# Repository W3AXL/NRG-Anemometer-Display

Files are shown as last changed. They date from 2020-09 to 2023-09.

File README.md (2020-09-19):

# NRG Anemometer Display
A compact, cheap interface unit for NRG #40C 3-cup anemometers.

<p float="left">
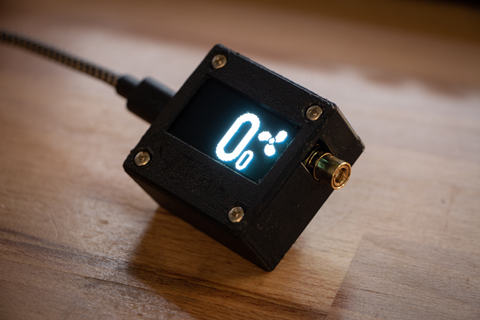
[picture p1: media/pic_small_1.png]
  
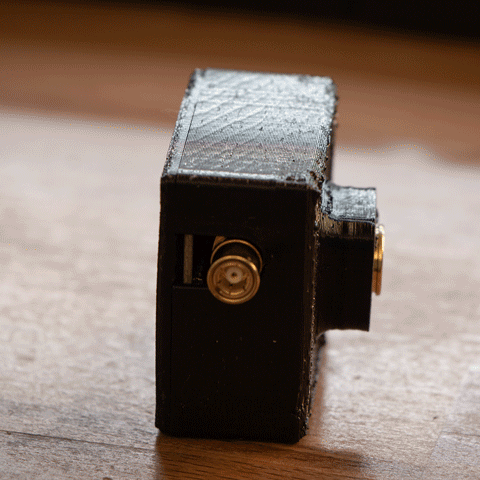
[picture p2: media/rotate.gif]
   
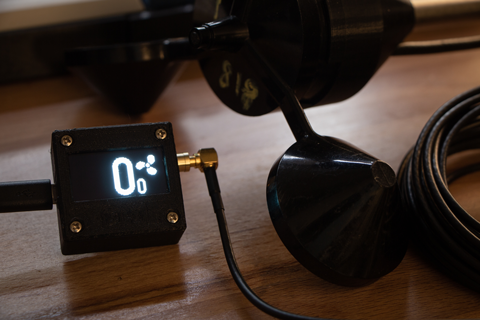
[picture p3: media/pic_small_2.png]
   
</p>

This project started because I found a great deal on some NRG anemometers on eBay. Two for $40 was hard to turn down, especially because each unit is calibrated from the factory and said calibration is freely available on [NRG's website](https://www.nrgsystems.com/support/product-support/calibration-reports/).

The heavy lifting of the circuit was already done for me - the technical whitepaper from NRG clearly illustrates an almost-complete schematic. The only real work to be done was selection of components, the MCU interfacing, and board design for a nice compact meter.

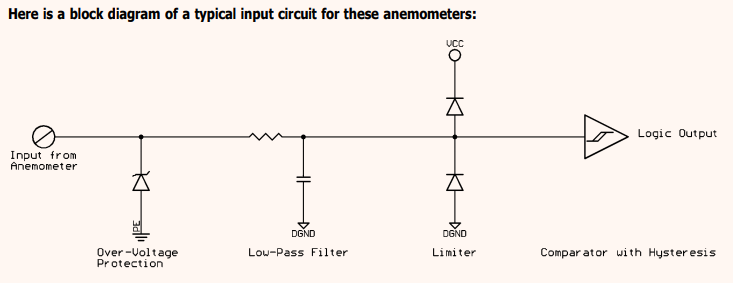
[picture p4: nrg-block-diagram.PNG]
NRG Block Diagram


I went through a lot of initial brainstorming for the interface concept - battery powered, or DC? Integrated data logging, or keep it simple? How many buttons? Should it beep at you annoyingly?

In the end, a dead-simple interface showing current and maximum wind readings was decided on. Power is provivded via a micro-USB plug, which also creates a serial port for real-time data transfer to a PC. The display is your standard run-of-the-mill eBay 1.3" OLED display, driven by I2C, and available for a few dollars all over the place. Boards were designed in Kicad and manufactured by JLCPCB. Components were sourced from Digikey, and the whole thing took a couple days to get working.



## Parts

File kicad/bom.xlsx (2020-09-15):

Ref | Qnty | Value | Cmp name | Footprint | Link | Description
C1, C2, C4, | 3 | 0.1uF | C_Small | C_0805 | Digikey (https://www.digikey.com/product-detail/en/avx-corporation/08055C104J4T2A/478-9380-1-ND/4901454) | Unpolarized capacitor, small symbol
C3, C5, C8, | 3 | 1uF | C_Small | C_0805 | Digikey (https://www.digikey.com/product-detail/en/avx-corporation/0805YC105JAT2A/478-10570-1-ND/6797609) | Unpolarized capacitor, small symbol
C6, C7, | 2 | 6.8pF | C_Small | C_0805 | Digikey (https://www.digikey.com/product-detail/en/avx-corporation/08055A6R8JAT2A/478-10540-1-ND/6797422) | Unpolarized capacitor, small symbol
D1, | 1 | 18V | D_TVS | SOD-323 | Digikey (https://www.digikey.com/product-detail/en/bourns-inc/CDSOD323-T18SC/CDSOD323-T18SCCT-ND/6679633) | Bidirectional transient-voltage-suppression diode
D2, | 1 | 3.3V | D_Zener_Small | SOD-323 | Digikey (https://www.digikey.com/product-detail/en/on-semiconductor/MM3Z3V3T1G/MM3Z3V3T1GOSCT-ND/2623467) | Zener diode, small symbol
F1, | 1 | 250mA | Fuse_Small | F_1206 | Digikey (https://www.digikey.com/product-detail/en/bel-fuse-inc/0ZCJ0025AF2E/507-1799-1-ND/4156322) | Polyfuse, 250mA hold current
J1, | 1 | OLED | Conn_01x04_Female | SMT 01x04 Female Recpt | Digikey (https://www.digikey.com/product-detail/en/samtec-inc/SLW-104-01-F-S/SAM9947-ND/6678684) | .180" Female Low Profile Socket, 0.1" Spacing
J2, | 1 | NRG | Conn_Coaxial | (Custom) Right Angle SMB Female Connector | Digikey (https://www.digikey.com/product-detail/en/adam-tech/RF3-04A-T-00-50-G/2057-RF3-04A-T-00-50-G-ND/9830852) | coaxial connector (BNC, SMA, SMB, SMC, Cinch/RCA, ...)
J3, | 1 | AVR-ISP-6 | AVR-ISP-6 | 1x6 0.1" Unsoldered Headers | n/a | Atmel 6-pin ISP connector
J4, | 1 | USB | USB_B_Micro | (Custom) Micro USB | Digikey (https://www.digikey.com/product-detail/en/amphenol-icc-fci/10118192-0001LF/609-4613-1-ND/2785378) | USB Micro Type B connector
R1, R2, R4, R6, | 4 | 10k | R_Small | R_0805 | Digikey (https://www.digikey.com/product-detail/en/yageo/RC0805FR-0710KL/311-10-0KCRCT-ND/730482) | Resistor, small symbol
R3, R5 | 2 | 100k | R_Small | R_0805 | Digikey (https://www.digikey.com/product-detail/en/yageo/RC0805FR-07100KL/311-100KCRCT-ND/730491) | Resistor, small symbol
R7, R8, | 2 | 22R | R_Small | R_0805 | Digikey (https://www.digikey.com/product-detail/en/yageo/RC0805FR-0722RL/311-22-0CRCT-ND/730682) | Resistor, small symbol
SW1, | 1 | RESET | SW_Push | PTS645 | Digikey (https://www.digikey.com/product-detail/en/c-k/PTS645SK43SMTR92-LFS/CKN9084CT-ND/1146821) | Push button switch, generic, two pins
U1, | 1 | LM321 | LM321 | SOT-23-5 | Digikey (https://www.digikey.com/product-detail/en/texas-instruments/LM321LVIDBVR/296-51261-1-ND/9745625) | Low Power Single Operational Amplifier, SOT-23-5
U2, | 1 | SN74LVC1G14DBV | SN74LVC1G14DBV | SOT-23-5 | Digikey (https://www.digikey.com/product-detail/en/texas-instruments/SN74LVC1G14DBVR/296-11607-1-ND/385746) | Single Schmitt-Trigger Inverter, SOT-23
U3, | 1 | ATmega32U4-AU | ATmega32U4-AU | TQFP-44 | Digikey (https://www.digikey.com/product-detail/en/microchip-technology/ATMEGA32U4RC-AU/ATMEGA32U4RC-AU-ND/2507982) | 16MHz, 32kB Flash, 2.5kB SRAM, 1kB EEPROM, USB 2.0, TQFP-44
U4, | 1 | XC6210B332MR-G | XC6210 | SOT-74A | Digikey (https://www.digikey.com/product-detail/en/torex-semiconductor-ltd/XC6210B332MR-G/893-1075-1-ND/2138266) | 3.3V LDO
Y1, | 1 | 8MHz | Crystal_Small | (Custom) SMD Crystal, 2-SMD | Digikey (https://www.digikey.com/product-detail/en/ndk-america-inc/NX8045GB-8-000000MHZ/644-1018-1-ND/1128890) | Two pin crystal, small symbol

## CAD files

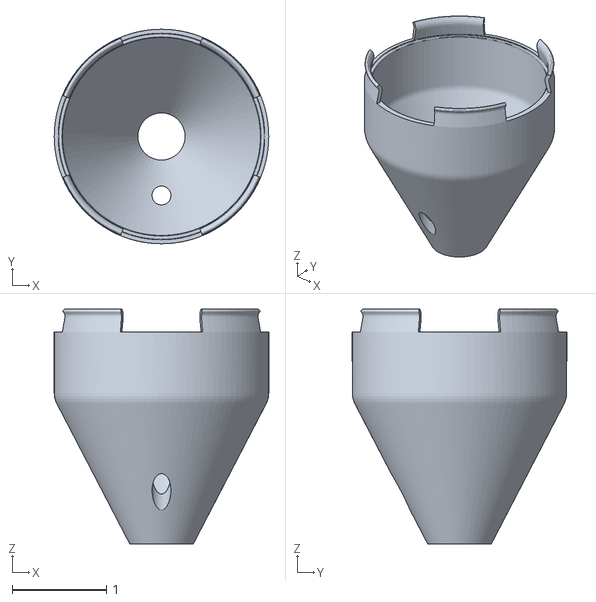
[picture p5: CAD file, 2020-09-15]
cad/anemometer shroud/shroud-revB.stl
2.28 x 2.28 x 2.49

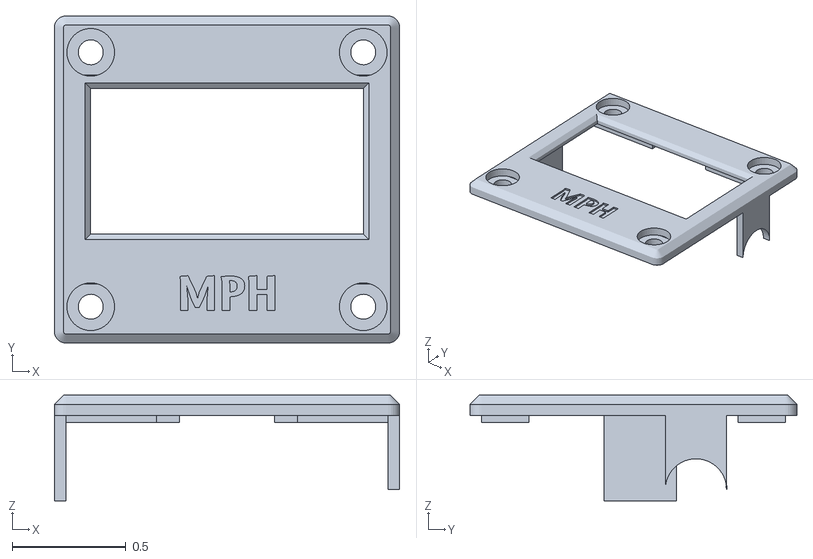
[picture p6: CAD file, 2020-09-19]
cad/enclosure/top-revA.stl
1.52 x 1.44 x 0.465

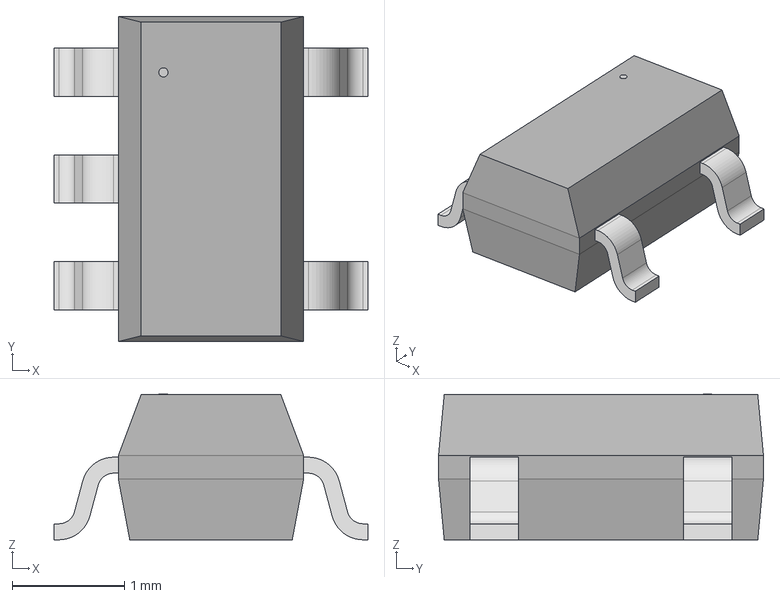
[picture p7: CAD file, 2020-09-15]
kicad/SOT-25_TOR.step
2.79 x 2.90 x 1.30 mm

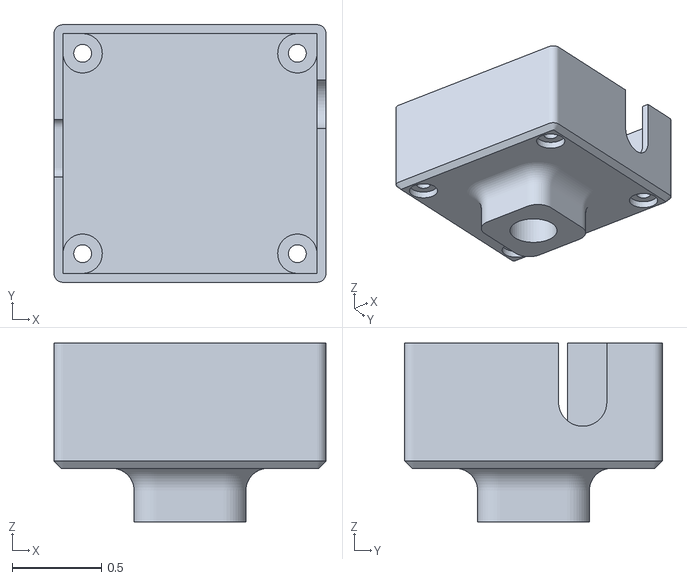
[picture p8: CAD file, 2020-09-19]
cad/enclosure/body-revA.stl
1.52 x 1.44 x 1.00

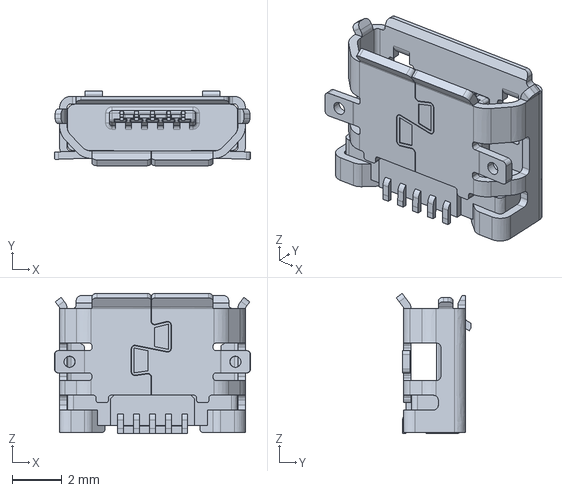
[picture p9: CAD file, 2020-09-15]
kicad/10118192C.stp
7.91 x 3.01 x 5.66 mm

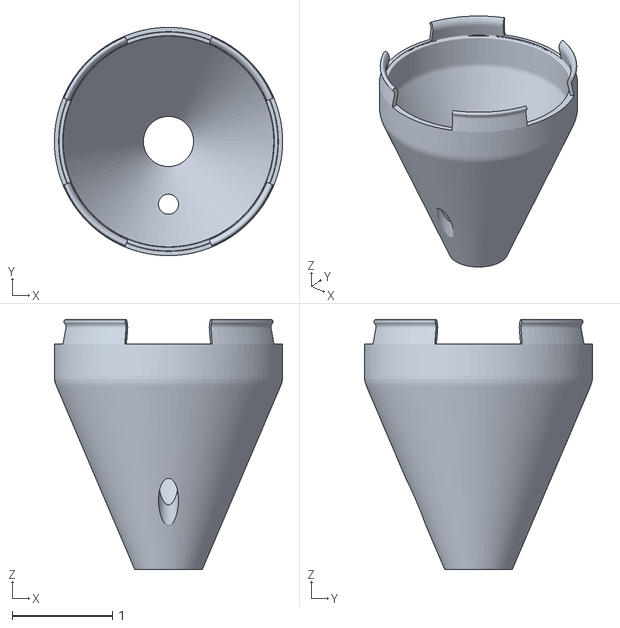
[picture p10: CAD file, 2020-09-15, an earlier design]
cad/anemometer shroud/shroud-revA.stl
2.28 x 2.28 x 2.49

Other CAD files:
kicad/SOT-25_TOR-M.step
kicad/SOT-25_TOR-L.step

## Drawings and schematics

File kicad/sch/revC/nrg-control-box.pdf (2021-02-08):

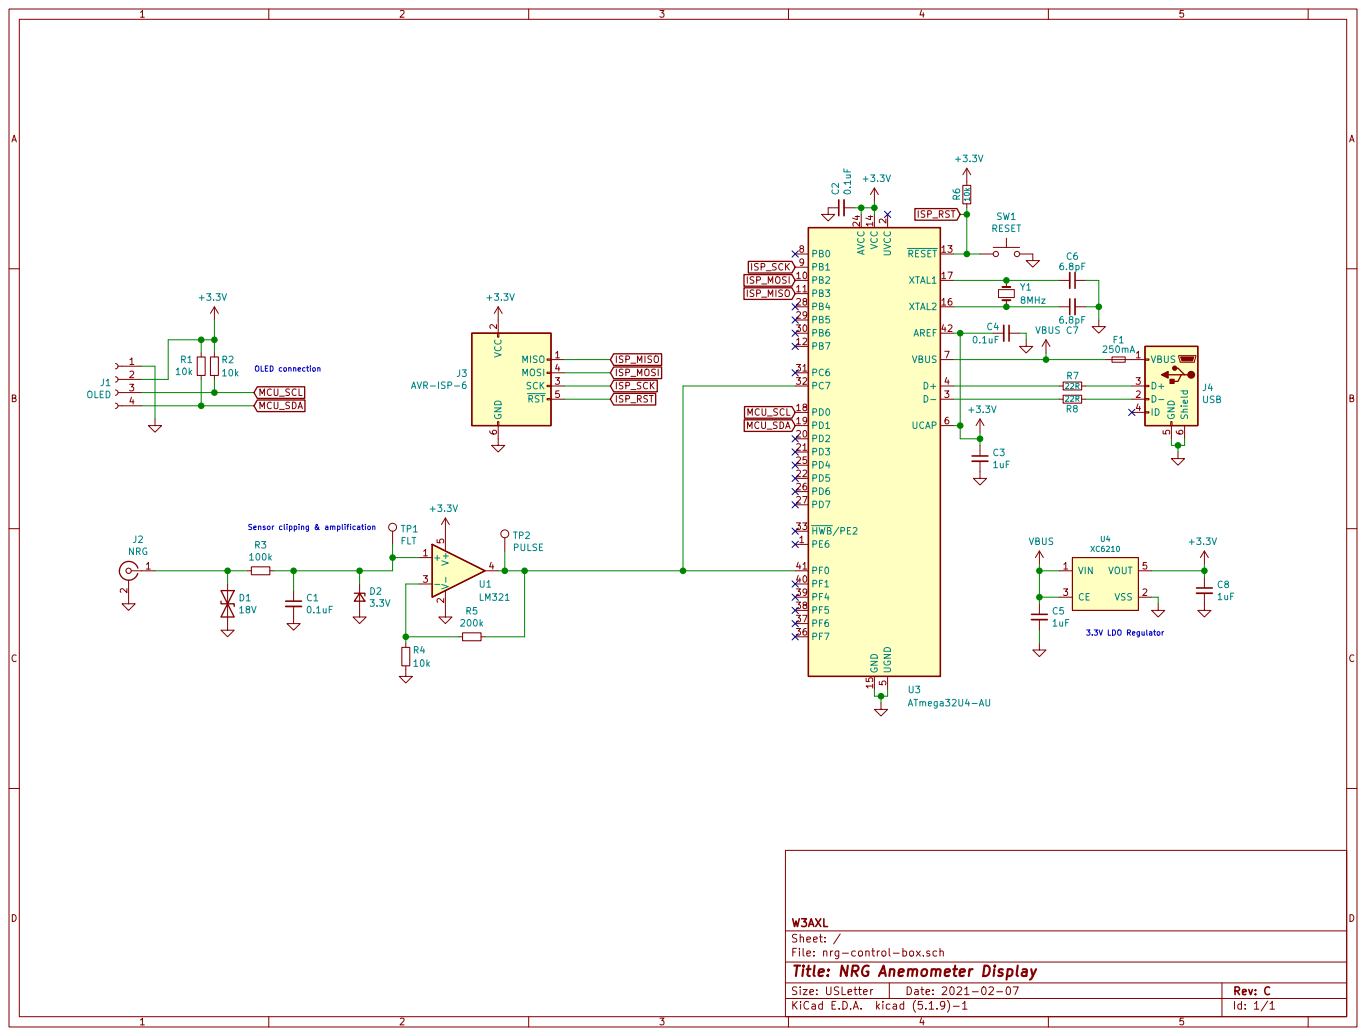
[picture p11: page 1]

2 SCK 3 MOSI 4 RST 5 GND

ISP_MISO MCU_SDA MCU_SCL
Sensor clipping & amplification OLED connection

File: nrg-control-box.sch Sheet: / W3AXL

Id: 1/1 Title: NRG Anemometer Display

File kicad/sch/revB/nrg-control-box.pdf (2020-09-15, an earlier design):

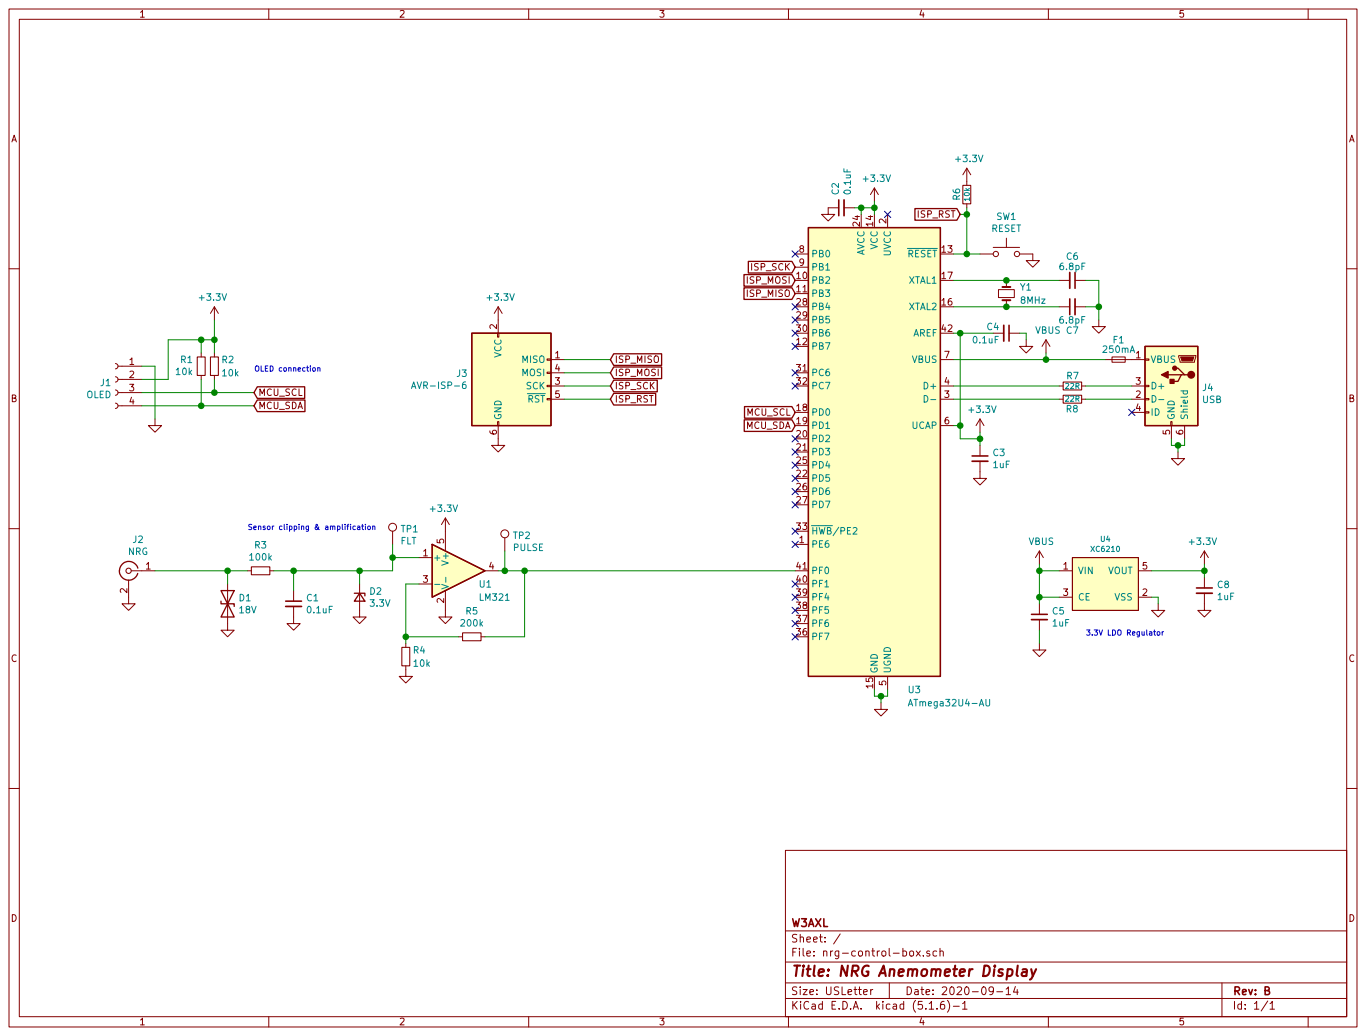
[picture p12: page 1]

2 SCK 3 MOSI 4 RST 5 GND

ISP_MISO MCU_SCL MCU_SDA
3.3V LDO Regulator OLED connection Sensor clipping & amplification

File: nrg-control-box.sch Sheet: / W3AXL

Id: 1/1 Title: NRG Anemometer Display

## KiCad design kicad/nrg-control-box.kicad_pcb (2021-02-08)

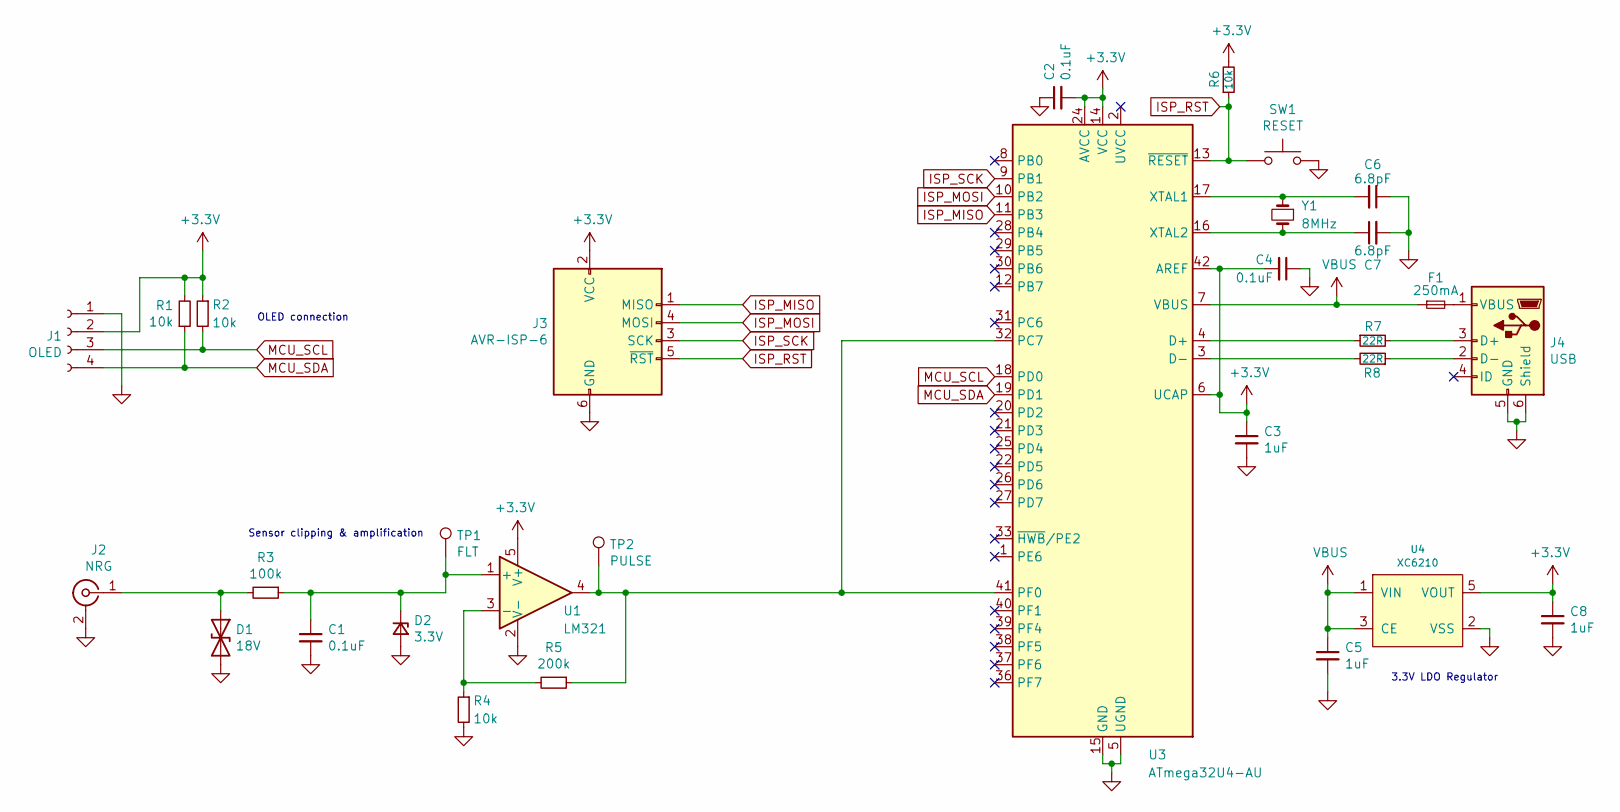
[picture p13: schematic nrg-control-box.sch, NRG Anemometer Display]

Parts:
C1, C2, C4: 0.1uF; C_0805_2012Metric_Pad1.15x1.40mm_HandSolder
C3, C5, C8: 1uF; C_0805_2012Metric_Pad1.15x1.40mm_HandSolder
C6, C7: 6.8pF; C_0805_2012Metric_Pad1.15x1.40mm_HandSolder
D1: 18V; D_SOD-323_HandSoldering
D2: 3.3V; D_SOD-323_HandSoldering
F1: 250mA; Fuse_1206_3216Metric_Pad1.42x1.75mm_HandSolder
J1: OLED; PinSocket_1x04_P2.54mm_Vertical
J2: NRG; RF3-04A-T-00-50-G
J3: AVR-ISP-6; PinSocket_1x06_P1.27mm_Vertical
J4: USB; 10118192-0001LF
R1, R2, R4, R6: 10k; R_0805_2012Metric_Pad1.15x1.40mm_HandSolder
R3: 100k; R_0805_2012Metric_Pad1.15x1.40mm_HandSolder
R5: 200k; R_0805_2012Metric_Pad1.15x1.40mm_HandSolder
R7, R8: 22R; R_0805_2012Metric_Pad1.15x1.40mm_HandSolder
SW1: RESET; SW_SPST_PTS645
TP1: FLT; TestPoint_Pad_1.0x1.0mm
TP2: PULSE; TestPoint_Pad_1.0x1.0mm
U1: LM321; SOT-23-5
U3: ATmega32U4-AU; TQFP-44_10x10mm_P0.8mm
U4: XC6210; SOT95P285X145-5N
Y1: 8MHz; NX8045GB

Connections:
+3V3: C2.2, C3.1, C4.2, C8.1, J1.2, J3.2 (VCC), R1.2, R2.1, R6.2, U1.5 (V+), U3.6 (UCAP), U3.14 (VCC), U3.24 (AVCC), U3.34 (VCC), U3.42 (AREF), U3.44 (AVCC), U4.5 (VOUT); also elsewhere on the board
GND: C1.2, C2.1, C3.2, C4.1, C5.2, C6.1, C7.2, C8.2, D1.2 (A2), D2.2 (A), J1.1, J2.2 (Ext), J3.6 (GND), J4.5 (GND), J4.6 (Shield), R4.2, SW1.2, U1.2 (V-), U3.5 (UGND), U3.15 (GND), U3.23 (GND), U3.35 (GND), U3.43 (GND), U4.2 (VSS); also elsewhere on the board
ISP_MISO: J3.1 (MISO), U3.11 (PB3)
ISP_MOSI: J3.4 (MOSI), U3.10 (PB2)
ISP_RST: J3.5 (~RST), R6.1, SW1.1, U3.13 (~RESET)
ISP_SCK: J3.3 (SCK), U3.9 (PB1)
MCU_SCL: J1.3, R2.2, U3.18 (PD0)
MCU_SDA: J1.4, R1.1, U3.19 (PD1)
unnamed: C1.1, D2.1 (K), R3.1, TP1.1, U1.1 (+)
unnamed: C6.2, U3.17 (XTAL1), Y1.1
unnamed: C7.1, U3.16 (XTAL2), Y1.2
unnamed: D1.1 (A1), J2.1 (In), R3.2
unnamed: F1.2, J4.1 (VBUS)
unnamed: J4.2 (D-), R8.1
unnamed: J4.3 (D+), R7.2
unnamed: R4.1, R5.2, U1.3 (-)
unnamed 17: R5.1, TP2.1, U1.4, U3.32 (PC7), U3.41 (PF0); also elsewhere on the board
unnamed: R7.1, U3.4 (D+)
unnamed: R8.2, U3.3 (D-)
VBUS: C5.1, F1.1, U3.7 (VBUS), U4.1 (VIN), U4.3 (CE)

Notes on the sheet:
Sensor clipping & amplification
OLED connection
3.3V LDO Regulator

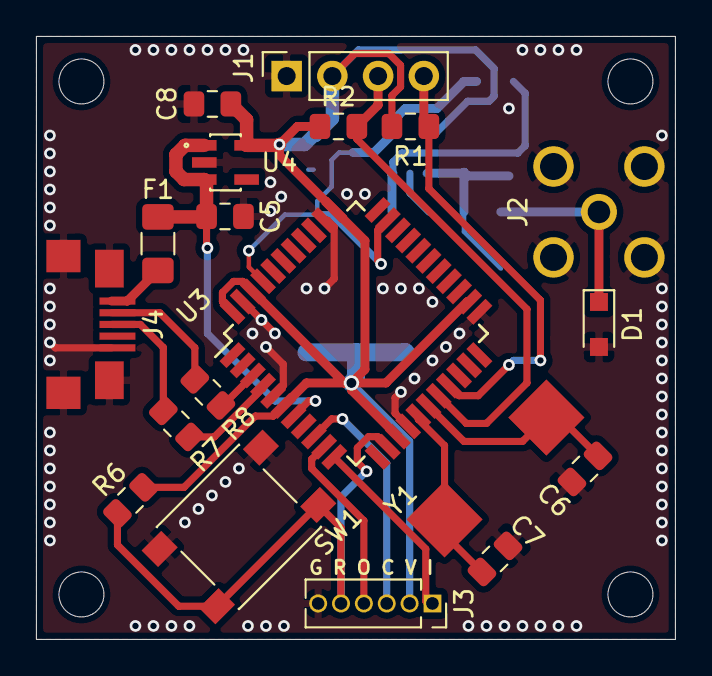
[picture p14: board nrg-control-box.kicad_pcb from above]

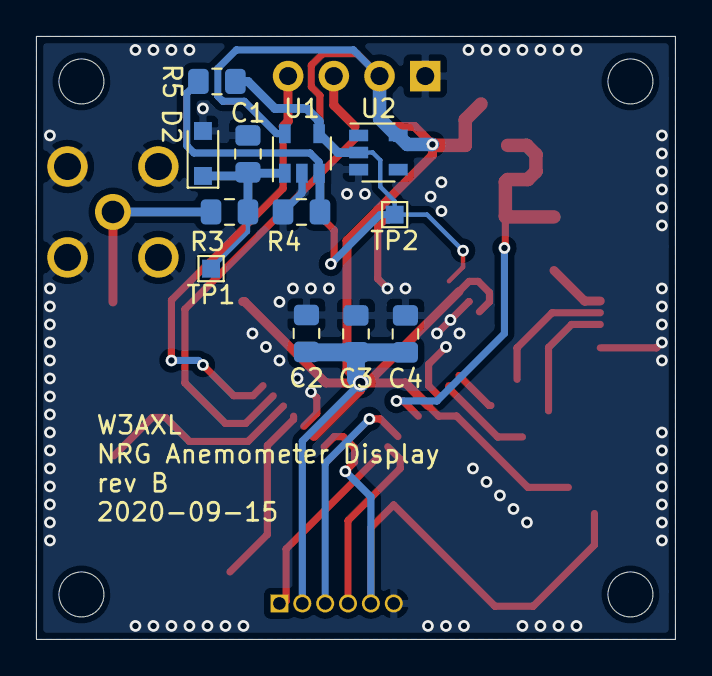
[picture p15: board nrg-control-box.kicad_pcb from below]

Board: 2 copper layers, 35.5 x 33.5 mm, 31 parts (12 on the bottom side), 20 nets.

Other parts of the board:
U2: SN74LVC1G14DBV; SOT-23-5

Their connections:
+3V3: U2.5; also elsewhere on the board
GND: U2.3; also elsewhere on the board
unnamed 17: U2.2; also elsewhere on the board

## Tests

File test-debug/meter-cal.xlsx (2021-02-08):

Freq | Meas | Ideal
1 | 3 | 2.53
3 | 6.00 | 5.92
5 | 9.00 | 9.32
7 | 13.00 | 12.71
9 | 16.00 | 16.11
11 | 20.00 | 19.50
13 | 23.00 | 22.90
15 | 26.00 | 26.30
17 | 30.00 | 29.69
19 | 33.00 | 33.09
21 | 36.00 | 36.48
23 | 40.00 | 39.88
25 | 43.00 | 43.27
27 | 47.00 | 46.67
29 | 50.00 | 50.06
31 | 53.00 | 53.46
33 |  | 56.86
35 |  | 60.25
37 |  | 63.65
39 |  | 67.04
41 |  | 70.44
43 |  | 73.83
45 |  | 77.23
47 |  | 80.63
49 |  | 84.02
51 |  | 87.42
53 |  | 90.81
55 |  | 94.21
57 |  | 97.60
59 |  | 101.00
61 |  | 104.40 | Cal Slope | 0.759
63 |  | 107.79 | Cal Offset | 0.37
65 |  | 111.19 | m/s to mph | 2.23694
67 |  | 114.58
69 |  | 117.98
71 |  | 121.37
73 |  | 124.77
75 |  | 128.17
77 |  | 131.56
79 |  | 134.96
81 |  | 138.35
83 |  | 141.75
85 |  | 145.14
87 |  | 148.54
89 |  | 151.94
91 |  | 155.33
93 |  | 158.73
95 |  | 162.12
97 |  | 165.52
99 |  | 168.91

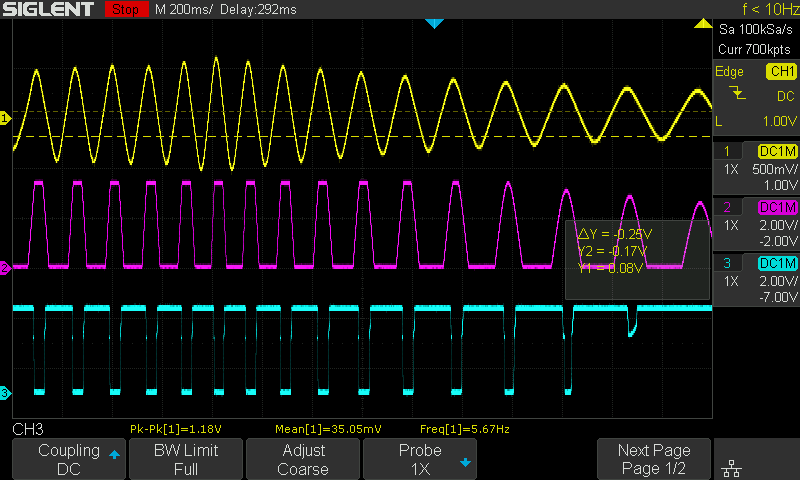
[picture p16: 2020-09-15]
test-debug/revA-analogChain-scope.png

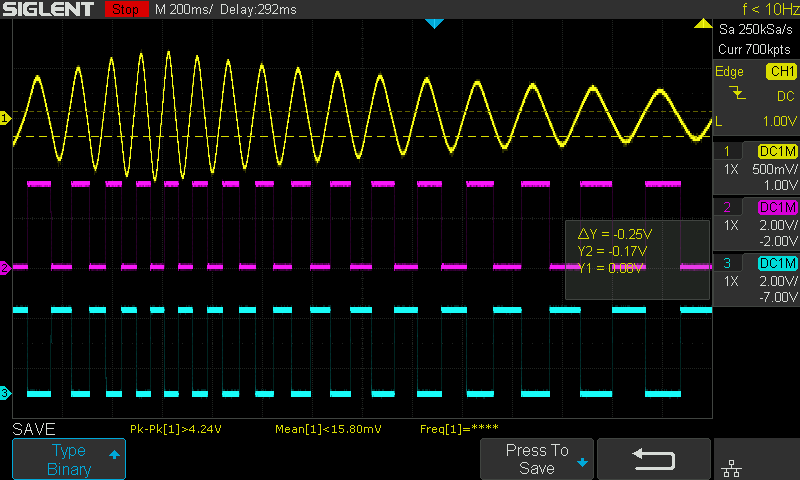
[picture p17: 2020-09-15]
test-debug/revB-analogChain-scope.png

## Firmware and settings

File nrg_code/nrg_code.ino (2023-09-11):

#include <U8g2lib.h>
#include <U8x8lib.h>

#include "fan3d.c" // fan bitmap

#include "src/FreqMeasure/FreqMeasure.h"

//#define DEBUGMODE

// compile time information
const char compile_date[] = __DATE__;
// version
const char swVersion[] = "1.1";

// Frequency Measurement Limits
#define MINFREQ 1     // approx 1.129 m/s or 2.5 mph
#define MAXFREQ 100   // approx 101.1 m/s or 226.2 mph

// Max speed reset timer in ms
#define RESETTIMEOUT (30*1000)

// Serial port report interval
#define REPORT_INTERVAL 2000

// Idle fan animation framerate
#define IDLE_ANIM_TIME 2000

// calibration data from NRG sensor
#define SLOPE 0.759
#define OFFSET 0.37

// conversion factor for m/s to mph
#define MPHFACTOR 2.23694

// storage for max freq
float maxFreq;

// storage for current speed in mph
char curSpeed;

// storage for max speed in mph
char maxSpeed;

// fan animation counter
unsigned char fanCount = 0;

// screen update timer
unsigned long lastUpdate = 0;

// serial report timer
unsigned long lastReport = 0;

// fan idle timeout
unsigned long lastIdle = 0;

// max speed reset vars
unsigned long lastMax = 0;

U8G2_SH1106_128X64_NONAME_F_HW_I2C u8g2(U8G2_R0);

void splashScreen() {
  u8g2.clearBuffer();
  u8g2.setFont(u8g2_font_9x15_tr);
  u8g2.setCursor(40,16);
  u8g2.print("Anemometer");
  u8g2.setCursor(40,30);
  u8g2.print("by W3AXL");
  u8g2.setCursor(4,44);
  u8g2.print("Version " + String(swVersion));
  u8g2.setCursor(4,58);
  u8g2.print(compile_date);
  u8g2.sendBuffer();
  // loading animation
  for (int i=0; i<100; i+=3) {
    u8g2.drawPixel(14+(i),63);
    u8g2.drawPixel(14+(i+1),63);
    u8g2.drawPixel(14+(i+2),63);
    u8g2.sendBuffer();
    switch (i%4) {
      case 0:
        u8g2.drawXBM(4,12,fan_width,fan_height,fan1_bits);
        break;
      case 1:
        u8g2.drawXBM(4,12,fan_width,fan_height,fan2_bits);
        break;
      case 2:
        u8g2.drawXBM(4,12,fan_width,fan_height,fan3_bits);
        break;
      case 3:
        u8g2.drawXBM(4,12,fan_width,fan_height,fan4_bits);
        break;
    }
  }
  delay(2000);
}

void debugScreen(float curFreq) {
  u8g2.clearBuffer();
  u8g2.setFont(u8g2_font_9x15_tr);
  u8g2.setCursor(4,12);
  u8g2.print("Cur Freq:");
  u8g2.setCursor(16,24);
  u8g2.print(String(curFreq));
  u8g2.setCursor(4,36);
  u8g2.print("Max Freq:");
  u8g2.setCursor(16,48);
  u8g2.print(String(maxFreq));
  u8g2.setCursor(4,60);
  u8g2.print("DEBUG MODE");
  u8g2.sendBuffer();
}

void updateScreen(int curMph, int maxMph) {
  // clear screen
  u8g2.clearBuffer();
  // print current speed, with extra sauce for right-justification
  String curSpd = String(int(curMph));
  u8g2.setFont(u8g2_font_logisoso54_tn);
  switch (curSpd.length()) {
    // single digit
    case 1:
      u8g2.setCursor(54,62);
      u8g2.print(curSpd);
      break;
    // two digits
    case 2:
      u8g2.setCursor(54,62);
      u8g2.print(curSpd[1]);
      u8g2.setCursor(24,62);
      u8g2.print(curSpd[0]);
      break;
    // three digits
    case 3:
      u8g2.setCursor(54,62);
      u8g2.print(curSpd[2]);
      u8g2.setCursor(24,62);
      u8g2.print(curSpd[1]);
      u8g2.setCursor(-3,62);
      u8g2.print(curSpd[0]);
      break;
  }
  // max speed
  u8g2.setFont(u8g2_font_logisoso20_tn);
  u8g2.setCursor(88,62);
  u8g2.print(String(int(maxMph)));
  // MPH text
  u8g2.setFont(u8g2_font_profont17_tr);
  u8g2.setCursor(90,37);
  u8g2.print("MPH");
  // Fan animation
  if (curMph > 0) {
    // increment the fan animation on screen update if our speed is not 0
    if (fanCount > 2) {
      fanCount = 0;
    } else {
      fanCount++;
    }
  } else {
    // Idle animation if speed is zero
    if ((millis() - lastIdle) > IDLE_ANIM_TIME) {
      lastIdle = millis();
      // switch between frames 0 and 1
      if (fanCount) {
        fanCount = 0;
      } else {
        fanCount = 1;
      }
    }
  }
  // display the proper fan graphic
  switch (fanCount) {
    case 0:
      u8g2.drawXBM(90,8,fan_width,fan_height,fan1_bits);
      break;
    case 1:
      u8g2.drawXBM(90,8,fan_width,fan_height,fan2_bits);
      break;
    case 2:
      u8g2.drawXBM(90,8,fan_width,fan_height,fan3_bits);
      break;
    case 3:
      u8g2.drawXBM(90,8,fan_width,fan_height,fan4_bits);
      break;
  }
  // send all that grafix shit
  u8g2.sendBuffer();
}

void setup() {
  // initialize frequency measurement
  FreqMeasure.begin();
  // Serial port init
  Serial.begin(115200);
  // display setup
  u8g2.begin();
  u8g2.clear();
  u8g2.setBusClock(400000);
  #ifndef DEBUGMODE
    splashScreen();
  #endif
}

void loop() {
  // update the screen if we have a new measurement available
  if (FreqMeasure.available()) {
    // get the latest measurement
    float freq = FreqMeasure.countToFrequency(FreqMeasure.read());
    // convert to mph from freq
    float rawSpeed = ((freq * SLOPE) + OFFSET) * MPHFACTOR;
    // round to nearest int by adding 0.5 before casting
    rawSpeed = rawSpeed + 0.5 - (rawSpeed<0);
    curSpeed = int(rawSpeed);
    // check if that's a new max
    if (curSpeed > maxSpeed) { 
      maxSpeed = curSpeed; 
      maxFreq = freq;
      lastMax = millis();
    } else if (millis() - lastMax > RESETTIMEOUT) {
      maxSpeed = curSpeed;
      maxFreq = freq;
      lastMax = millis();
    }
    // update the screen
    #ifdef DEBUGMODE
      debugScreen(freq);
    #else
      updateScreen(curSpeed, maxSpeed);
    #endif
    // record the screen update time
    lastUpdate = millis();
  // if we haven't gotten a frequency update in longer than the minimum measurement period, update the screen
  } else if (millis() - lastUpdate > (1000/MINFREQ)) {
    // also reset our max if it's time
    if (millis() - lastMax > RESETTIMEOUT) {
      maxSpeed = 0;
      maxFreq = 0;
      lastMax = millis();
    }
    updateScreen(0, maxSpeed);
  }
  // Send serial report update if we can
  if (Serial.availableForWrite() > 16) {
    if (millis() - lastReport > REPORT_INTERVAL) {
      char buf[16];
      sprintf(buf, "CUR:%u,MAX:%u", curSpeed, maxSpeed);
      Serial.println(buf);
      lastReport = millis();
    }
  }
}

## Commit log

2020-09-15 initial github commit
    commit includes revision B of schematic and PCB, as well as version 0.1 of code
    [10118192C.stp, SOT-25_TOR-L.step, SOT-25_TOR-M.step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]
2020-09-17 switched from millis() to micros() for timing, simplified moving average
    [meter-cal.xlsx]
2020-09-19 added enclosure CAD files and media
    [body-revA.stl, top-revA.stl]
2021-02-07 completed initial work on SW using FreqMeasure library. Required rewiring of board to pin PC7, will update in future SCH revision
    [meter-cal.xlsx]
2021-02-08 finalized code using FreqMeasure
    updated code to use Teensy FreqMeasure library listening on pin PC7. Still todo is schematic updates to reflect this change.
2021-02-08 updated schematic to reflect change in measurement pin to PC7
    [nrg-control-box-B_Cu.gbr, nrg-control-box-B_Mask.gbr, nrg-control-box-B_SilkS.gbr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]
